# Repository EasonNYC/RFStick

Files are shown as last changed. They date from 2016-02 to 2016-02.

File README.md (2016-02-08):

# RFStick
A small IoT PCB for the Atmega 328p with Lipo charger and Battery Gas Gauge with an on-board 2.4GHz RF transceiver.

Author: Eason Smith (Eason@EasonRobotics.com)

Written with Cadsoft Eagle v7.2

This project is currently in developement. 

For more project details please visit: http://www.easonrobotics.com/?portfolio=rf-stick

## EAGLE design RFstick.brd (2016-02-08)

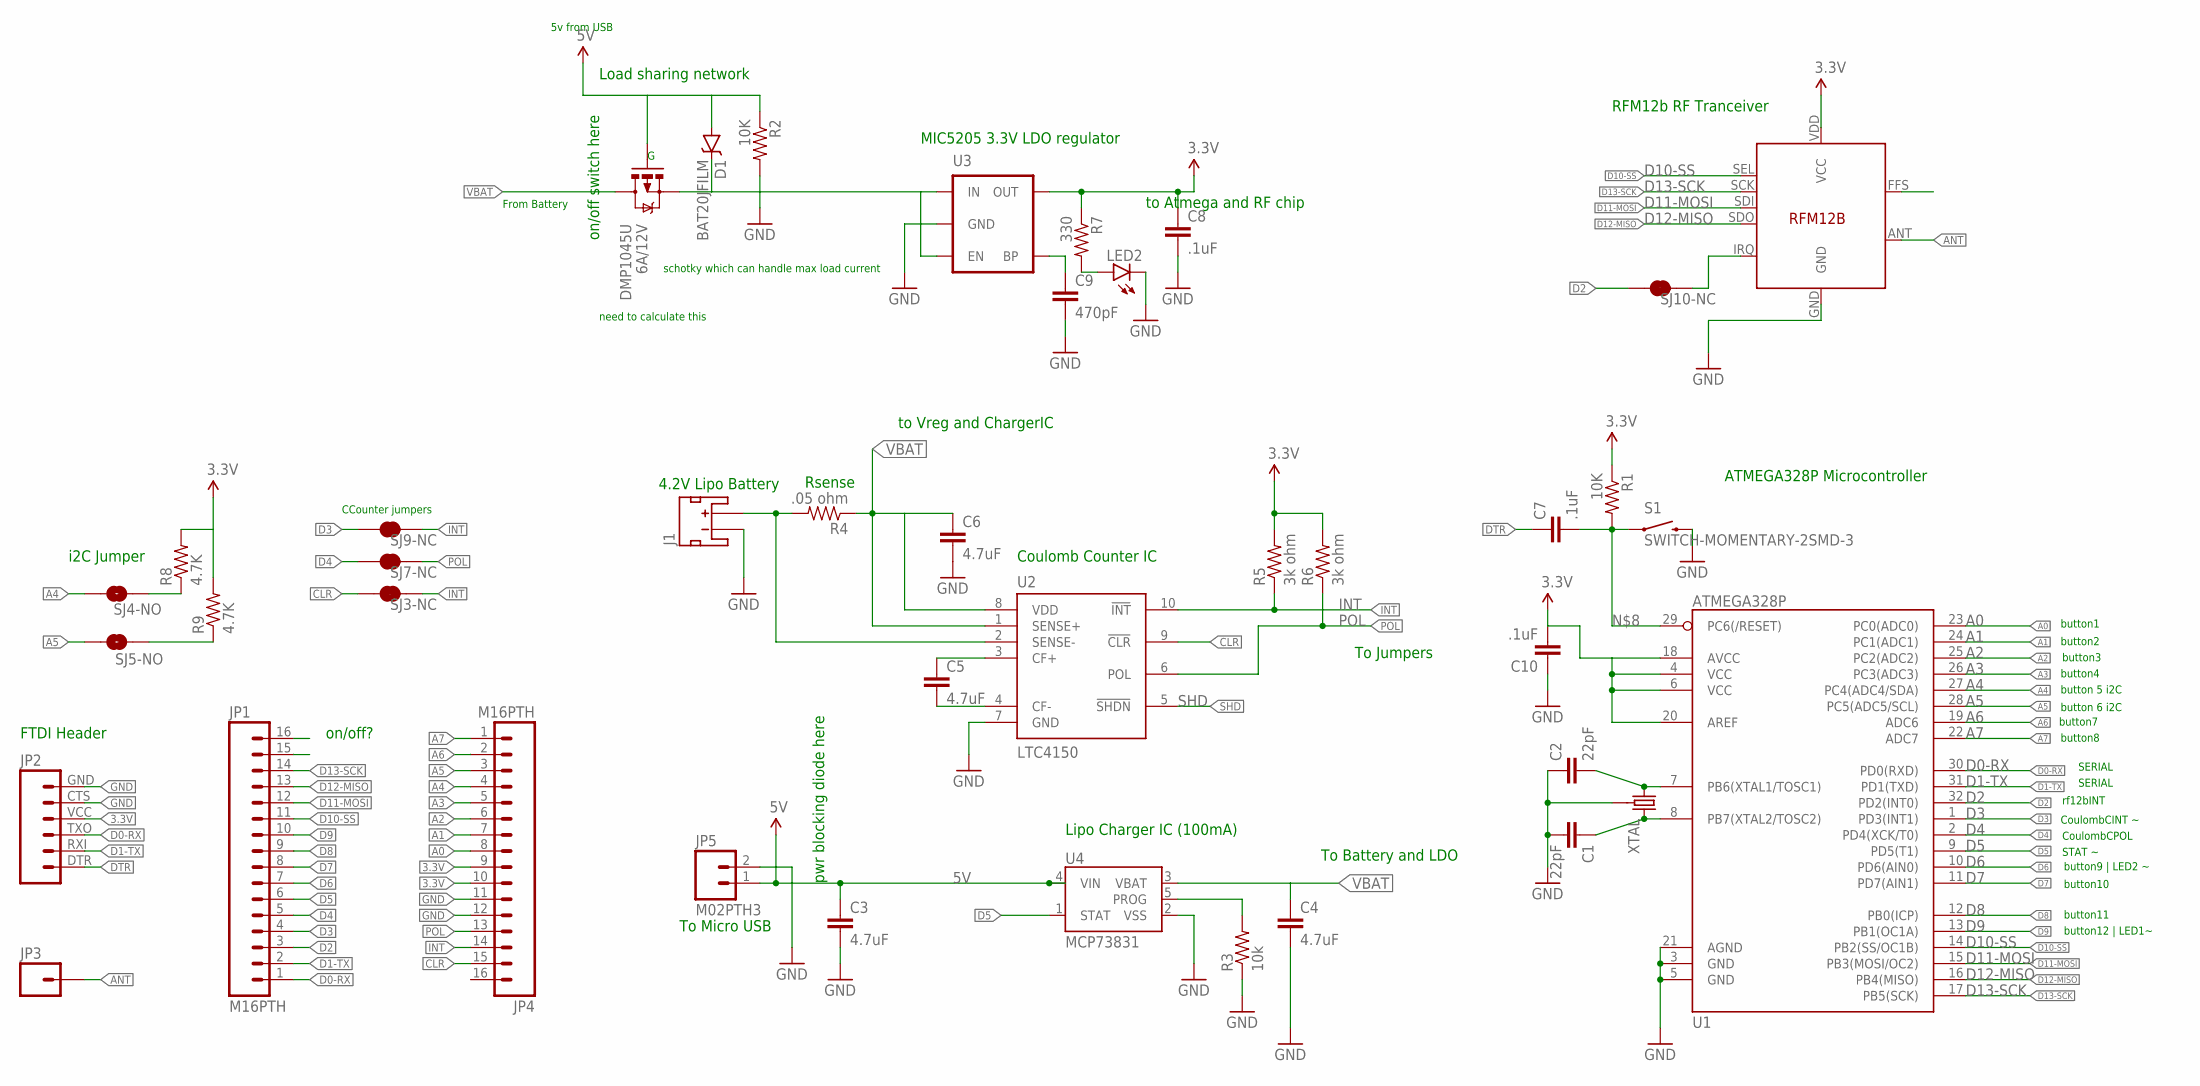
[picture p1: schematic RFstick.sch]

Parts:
C1, C2: 22pF; 0603-CAP; MPN 04025A220JAT2A
C3, C4, C5, C6: 4.7uF; 0603-CAP; MPN F981A475MMA
C7, C8, C10: .1uF; 0603-CAP; MPN MC0603B104M500CT
C9: 470pF; 0603-CAP; MPN 06031C471JAT2A
D1: BAT20JFILM; SOD-323
DMP1045U: 6A/12V; SOT23-3
J1: JST_2MM_MALE; JST-2-SMD
JP1, JP4: M16PTH; 1X16
JP2: M06SIP; 1X06
JP3: M01PTH; 1X01
JP5: M02PTH3; 1X02_LONGPADS
LED2: LED0603; LED-0603; MPN 150060RS75000
R1, R2: 10K; 0603-RES; MPN CRCW060310K0FKEAHP
R3: 10k; 0603-RES; MPN CRCW06032K00FKEA
R4: .05 ohm; 0603-RES; MPN MC0063W060311R0
R5, R6: 3k ohm; 0603-RES; MPN SR1-0603-230
R7: 330; 0603-RES
R8, R9: 4.7K; 0603-RES; MPN CRCW06034K70FKEA
S1: SWITCH-MOMENTARY-2SMD-3; TACTILE_SWITCH_SMD-3
SJ3-NC, SJ7-NC, SJ9-NC, SJ10-NC: JUMPER-PAD-2-NC_BY_TRACENO_SILK; PAD-JUMPER-2-NC_BY_TRACE_NO_SILK
SJ4-NO, SJ5-NO: JUMPER-PAD-2-NO; PAD-JUMPER-2-NO_NO_SILK
U1: ATMEGA328P; TQFP32-08
U2: LTC4150; MSOP10; MPN LTC4150CMS#PBF
U3: MIC52053.3V; SOT23-5; MPN MIC5205-3.3YM5 TR
U4: MCP73831; SOT23-5; MPN MCP73831T-2ACI/OT
U$1: XTAL; CRYSTAL-SMD-5X3; MPN AA-16.000MALE-T
U$2: RFM12B

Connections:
3.3V: C8.1, C10.2, JP2.VCC (4), JP4.9, JP4.10, R1.1, R5.2, R6.2, R7.1, R8.2, R9.2, U1.4 (VCC), U1.6 (VCC), U1.18 (AVCC), U1.20 (AREF), U3.5 (OUT), U$2.VDD (VCC)
5V: C3.1, D1.A, DMP1045U.1 (G), JP5.1, R2.1, U4.4 (VIN)
A0: JP4.8, U1.23 (PC0(ADC0))
A1: JP4.7, U1.24 (PC1(ADC1))
A2: JP4.6, U1.25 (PC2(ADC2))
A3: JP4.5, U1.26 (PC3(ADC3))
A4: JP4.4, SJ4-NO.1, U1.27 (PC4(ADC4/SDA))
A5: JP4.3, SJ5-NO.1, U1.28 (PC5(ADC5/SCL))
A6: JP4.2, U1.19 (ADC6)
A7: JP4.1, U1.22 (ADC7)
ANT: JP3.1, U$2.ANT
CLR: JP4.15, SJ3-NC.1, U2.9 (!CLR!)
D0-RX: JP1.1, JP2.TXO (3), U1.30 (PD0(RXD))
D1-TX: JP1.2, JP2.RXI (2), U1.31 (PD1(TXD))
D2: JP1.3, SJ10-NC.1, U1.32 (PD2(INT0))
D3: JP1.4, SJ9-NC.1, U1.1 (PD3(INT1))
D4: JP1.5, SJ7-NC.1, U1.2 (PD4(XCK/T0))
D5: JP1.6, U1.9 (PD5(T1)), U4.1 (STAT)
D6: JP1.7, U1.10 (PD6(AIN0))
D7: JP1.8, U1.11 (PD7(AIN1))
D8: JP1.9, U1.12 (PB0(ICP))
D9: JP1.10, U1.13 (PB1(OC1A))
D10-SS: JP1.11, U1.14 (PB2(SS/OC1B)), U$2.SEL
D11-MOSI: JP1.12, U1.15 (PB3(MOSI/OC2)), U$2.SDI
D12-MISO: JP1.13, U1.16 (PB4(MISO)), U$2.SDO
D13-SCK: JP1.14, U1.17 (PB5(SCK)), U$2.SCK
DTR: C7.1, JP2.DTR (1)
GND: C1.2, C2.1, C3.2, C4.2, C6.2, C8.2, C9.2, C10.1, J1.1 (-), JP2.CTS (5), JP2.GND (6), JP4.11, JP4.12, JP5.2, LED2.C, R2.2, R3.1, S1.4 (2), U1.3 (GND), U1.5 (GND), U1.21 (AGND), U2.7 (GND), U3.2 (GND), U4.2 (VSS), U$1.2 (3), U$1.4 (3), U$2.GND
INT: JP4.14, R5.1, SJ3-NC.2, SJ9-NC.2, U2.10 (!INT!)
unnamed: C1.1, U1.8 (PB7(XTAL2/TOSC2)), U$1.1 (2)
unnamed: C2.2, U1.7 (PB6(XTAL1/TOSC1)), U$1.3 (1)
unnamed: R3.2, U4.5 (PROG)
unnamed: C5.1, U2.3 (CF+)
unnamed: LED2.A, R7.2
unnamed: C7.2, R1.2, S1.1, U1.29 (PC6(/RESET))
unnamed: C5.2, U2.4 (CF-)
unnamed: J1.2 (+), R4.2, U2.2 (SENSE-)
unnamed: C9.1, U3.4 (BP)
unnamed: R8.1, SJ4-NO.2
unnamed: R9.1, SJ5-NO.2
unnamed: D1.C, DMP1045U.2 (S), U3.1 (IN), U3.3 (EN)
unnamed: SJ10-NC.2, U$2.IRQ
POL: JP4.13, R6.1, SJ7-NC.2, U2.6 (POL)
SHD: U2.5 (!SHDN!)
VBAT: C4.1, C6.1, DMP1045U.3 (D), R4.1, U2.1 (SENSE+), U2.8 (VDD), U4.3 (VBAT)

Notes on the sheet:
MIC5205 3.3V LDO regulator
Coulomb Counter IC
Lipo Charger IC (100mA)
To Micro USB
4.2V Lipo Battery
to Vreg and ChargerIC
to Atmega and RF chip
pwr blocking diode here
Rsense
i2C Jumper
FTDI Header
To Battery and LDO
rf12bINT
CoulombCINT ~
CCounter jumpers
button 5 i2C
button 6 i2C
SERIAL
CoulombCPOL
STAT ~
button9 | LED2 ~
button10
button11
button12 | LED1~
button1
button2
button3
button4
button7
button8
To Jumpers
From Battery
5v from USB
schotky which can handle max load current
Load sharing network
need to calculate this
RFM12b RF Tranceiver
ATMEGA328P Microcontroller
on/off switch here
on/off?

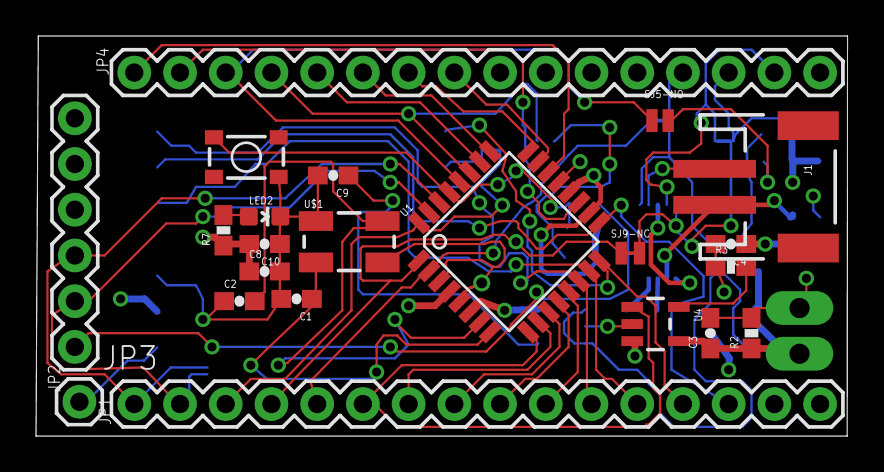
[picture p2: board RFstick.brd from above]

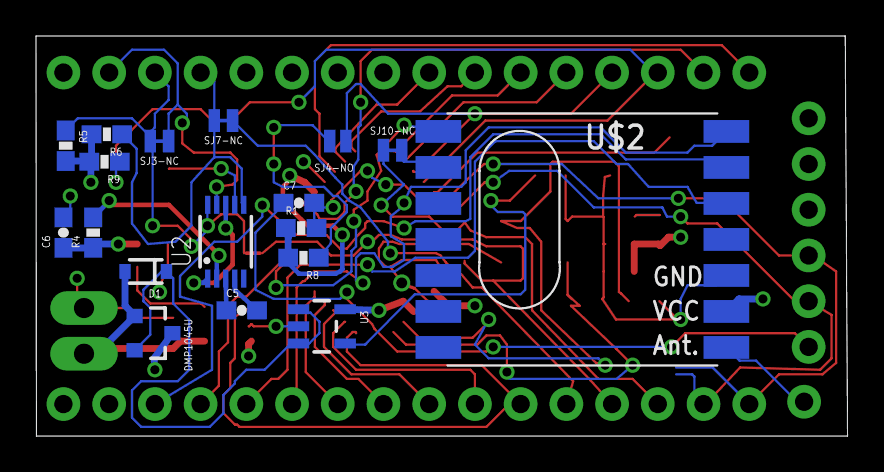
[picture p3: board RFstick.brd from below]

Board: 4 copper layers, 45.1 x 22.2 mm, 41 parts (18 on the bottom side), 44 nets.

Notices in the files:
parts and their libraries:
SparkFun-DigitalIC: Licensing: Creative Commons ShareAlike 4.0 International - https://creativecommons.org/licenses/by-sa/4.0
